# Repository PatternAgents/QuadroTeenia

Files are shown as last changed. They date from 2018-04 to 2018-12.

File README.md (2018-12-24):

# QuadroTeenia - A multi-channel, polymorphic audio module

Deprecated - see [Spoken into the Void](https://github.com/PatternAgents/SitV) for the current development version!



Format : ERA / Eurorack / (Dual) Breadboard Friendly

Height : 3U 

Width: 16HP

Depth : 1.0 cm

Power : +5V (USB) 200mA

Jacks : 3.5mm Jacks (CUI SJ1)

The QuadroTeenia is a low cost, embeddable audio module based on the Teensy 3.5/3.6 from PJRC :

* Embedded Rack Architecture (Eurorack 3U/16HP compatible)
* Teensy 3.6 Based (32 bit 180 MHz ARM Cortex-M4 processor with floating point unit and DSP)
* USB Full-Speed Device (USB Audio, MIDI, COM, HID)
* USB Full-Speed Host (USB Keyboard, peripherals)
* Two  (2) AC coupled, line level audio input channels 
* Four (4) AC coupled, line level audio output channels
* Four (4) DC coupled, ADC input channels
* Four (4) DC coupled, DAC output channels
* Four (4) DC coupled  Trigger input channels
* Four (4) DC coupled  Trigger output channels
* Dual (2) Flash/SRAM footprints for audio buffer (delay, echo, loop) memeories
* NVSRAM (non-volatile memory) for configuration memory (Embedis support)
* WS2812 Programmable RGB LED with output chain drivers
* Add optional "Quadro" boards for ERA and Eurorack jacks and interfaces
* Add optional Front-Panel board for mounting in ERA and/or Eurorack enclosures

QuadroTeenia Midi (https://www.youtube.com/watch?v=CV_AIyOy-t4)

QuadroTeenia (https://www.youtube.com/watch?v=xMB5RRlq_T8)

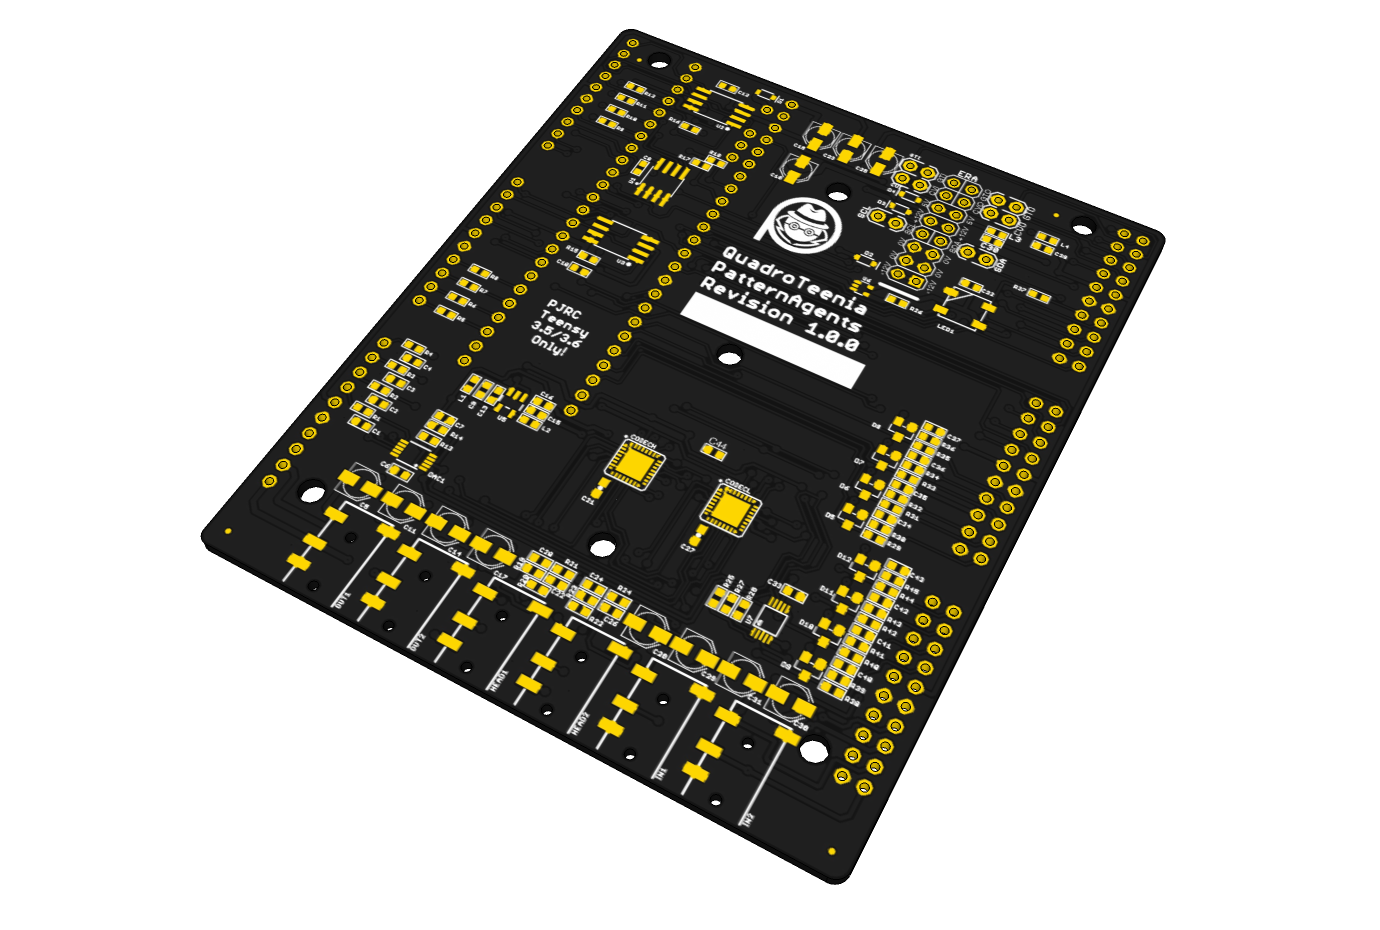
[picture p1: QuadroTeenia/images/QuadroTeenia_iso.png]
patternagents QuadroTeenia
[QuadroTeenia](https://github.com/patternagents/QuadroTeenia)

---------------------------------------
## QuadroTeenia Applications <a name="QuadroTeenia_Applications"/>

* Audio record/playback "trigger" device - 
  record/play samples based on external triggers

Add "Quadro" optional components and boards for :
* USB/MIDI to Eurorack Audio/CV/Control/Trigger
* Eurorack Multi-Sample Player
* Eurorack Sequencer
* Eurorack Reverb/Echo/Delay/Flanger (add SRAM)
* Eurorack Complex Filter (add SRAM)

---------------------------------------
## QuadroTeenia Status <a name="QuadroTeenia_Status"/>

**4/06/2018:** 
Revision 1.0.0 - Initial Layout received from OSHpark

**5/1/2018:**
Revision 1.0.0 
1) About 90% functional on first revision.
2) SGTL5000 routes too long, footprint issues, not functional

**5/11/2018:**
Revision 1.0.0
1) Midi I/O running, initial Midi-CV app

---------------------------------------
## QuadroTeenia Model Images

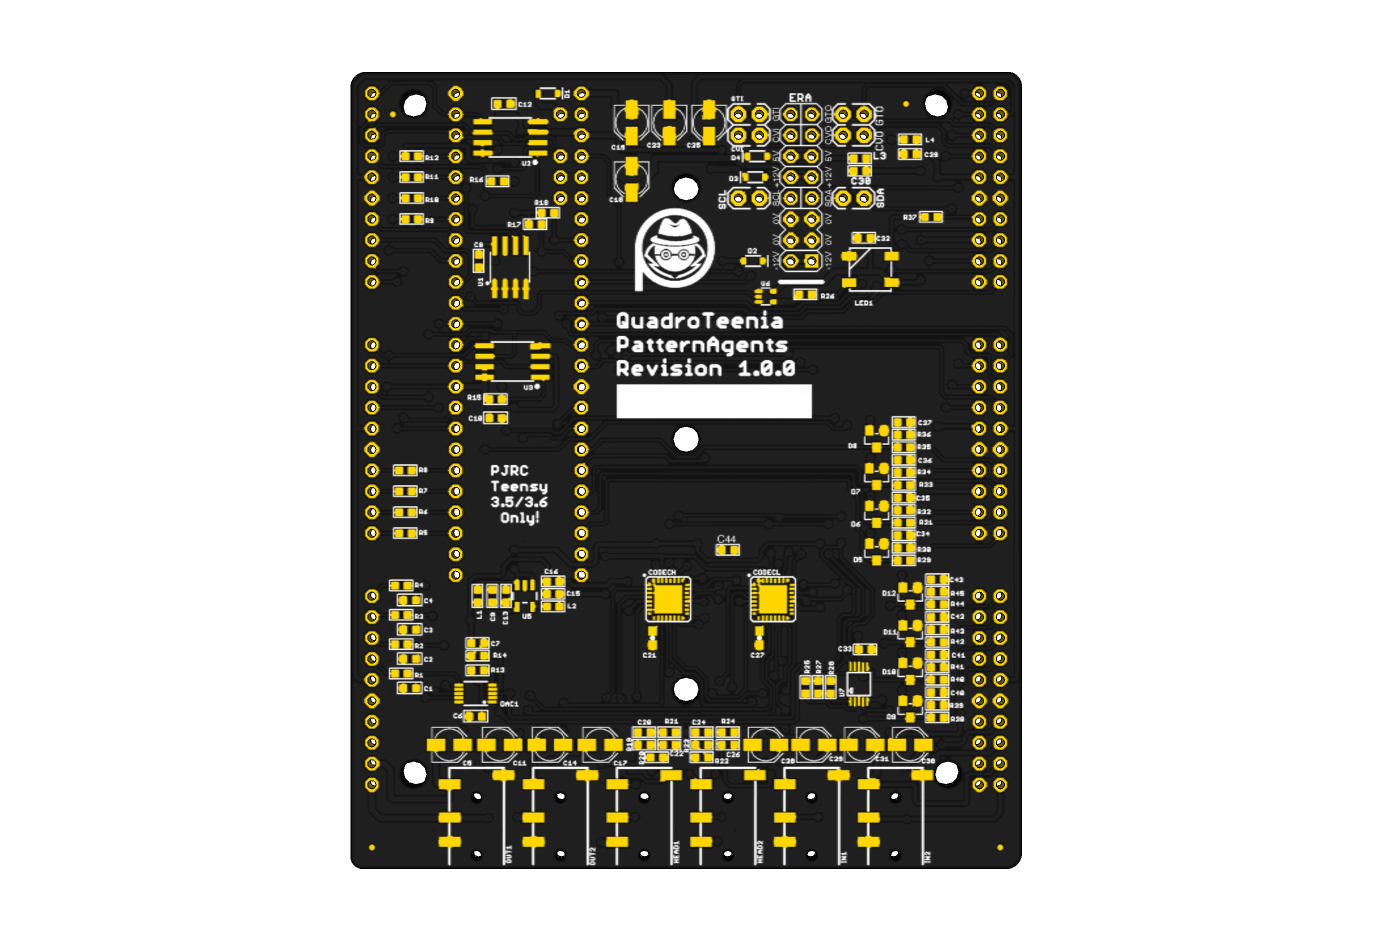
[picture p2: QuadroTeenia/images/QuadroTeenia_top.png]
patternagents QuadroTeenia
[QuadroTeenia](https://github.com/patternagents/QuadroTeenia)

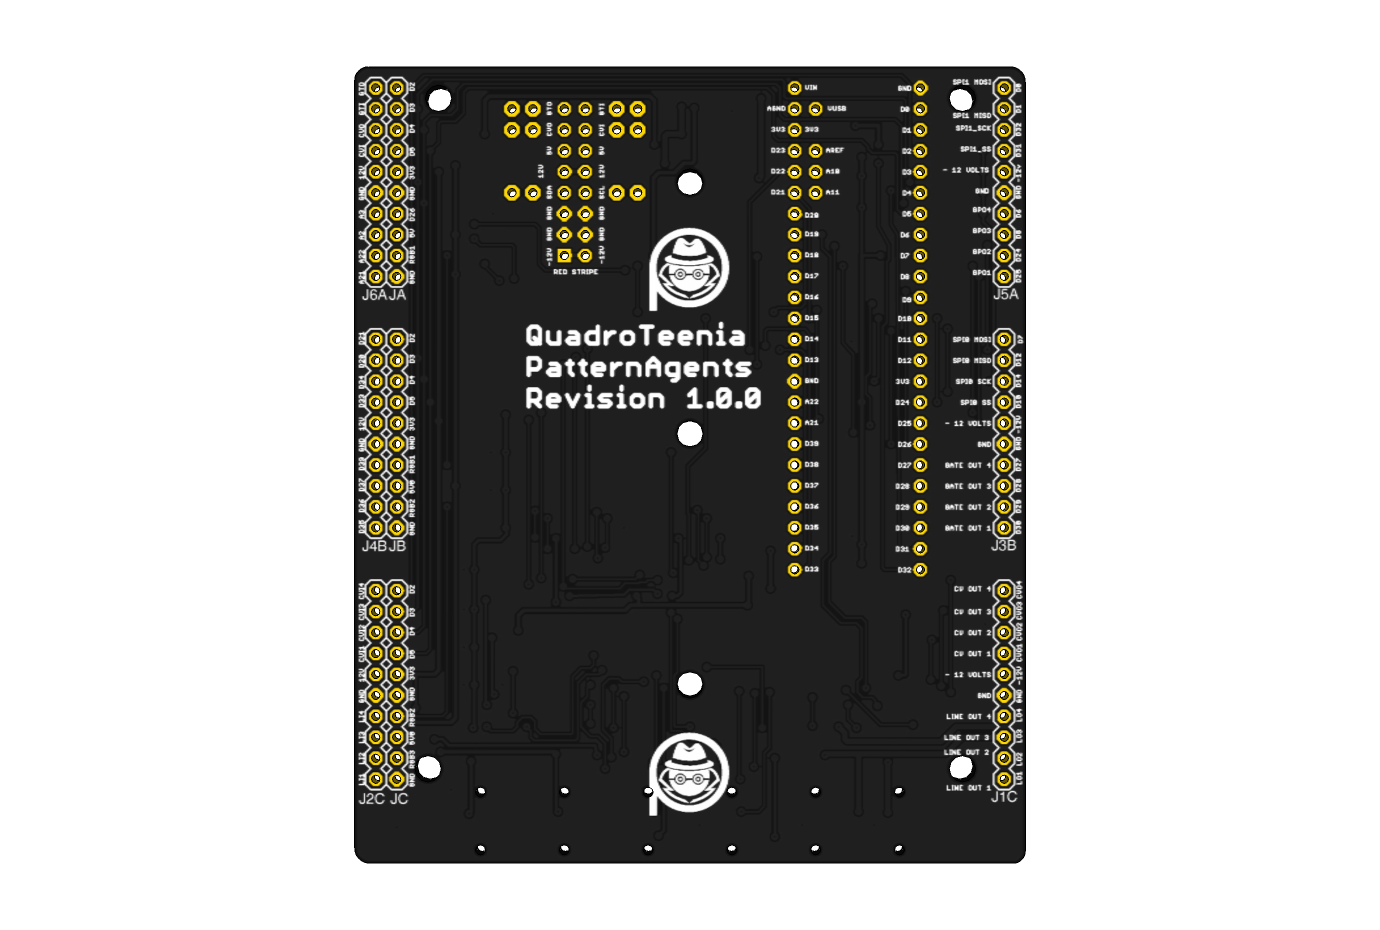
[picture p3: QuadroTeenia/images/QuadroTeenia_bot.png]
patternagents QuadroTeenia
[QuadroTeenia](https://github.com/patternagents/QuadroTeenia)

---------------------------------------

## QuadroTeenia Documentation Index <a name="QuadroTeenia_documentation_index"/>

[QuadroTeenia Project](https://github.com/PatternAgents/QuadroTeenia)

[QuadroTeenia Hardware](https://github.com/patternagents/QuadroTeenia/tree/master/QuadroTeenia/revisions/R1_0_0/)

---------------------------------------

## Documentation Index <a name="documentation_index"/>

[Organization Website](http://patternagents.github.io)

[FAQ - Frequently Asked Questions](http://thingsoc.github.io/support/faq.html)

---------------------------------------

[thingSoC 
*PatternAgents, LLC*](http://thingsoc.github.io)

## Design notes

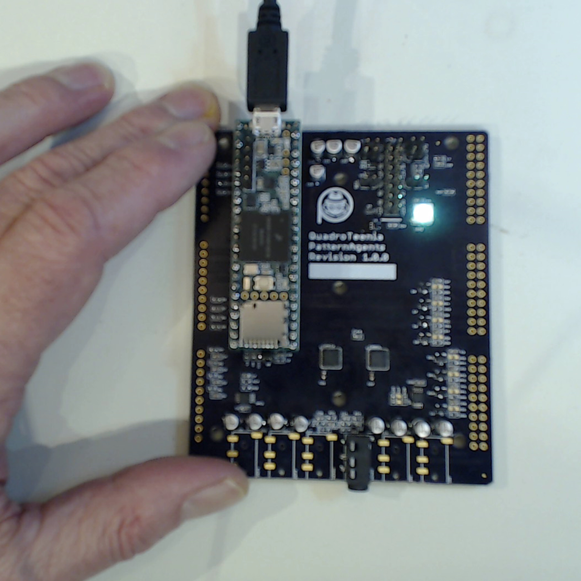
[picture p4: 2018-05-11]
QuadroTeenia/images/QuadroTeenia_Day1.png

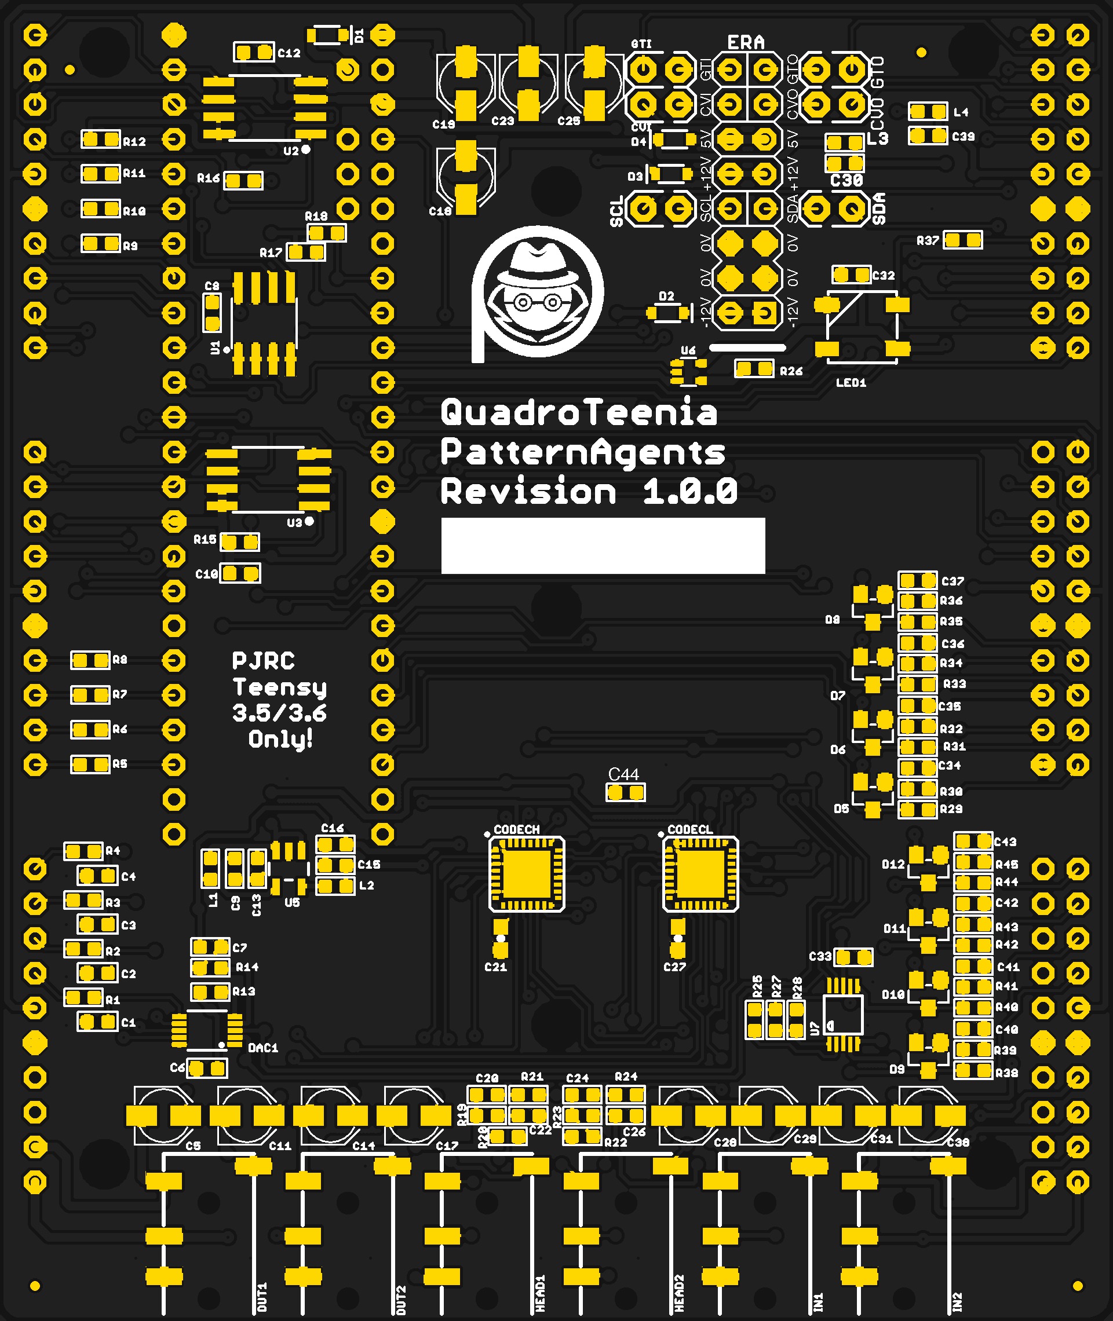
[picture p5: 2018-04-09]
QuadroTeenia/eagleUp/eagleUp_QuadroTeenia_board_top.jpg

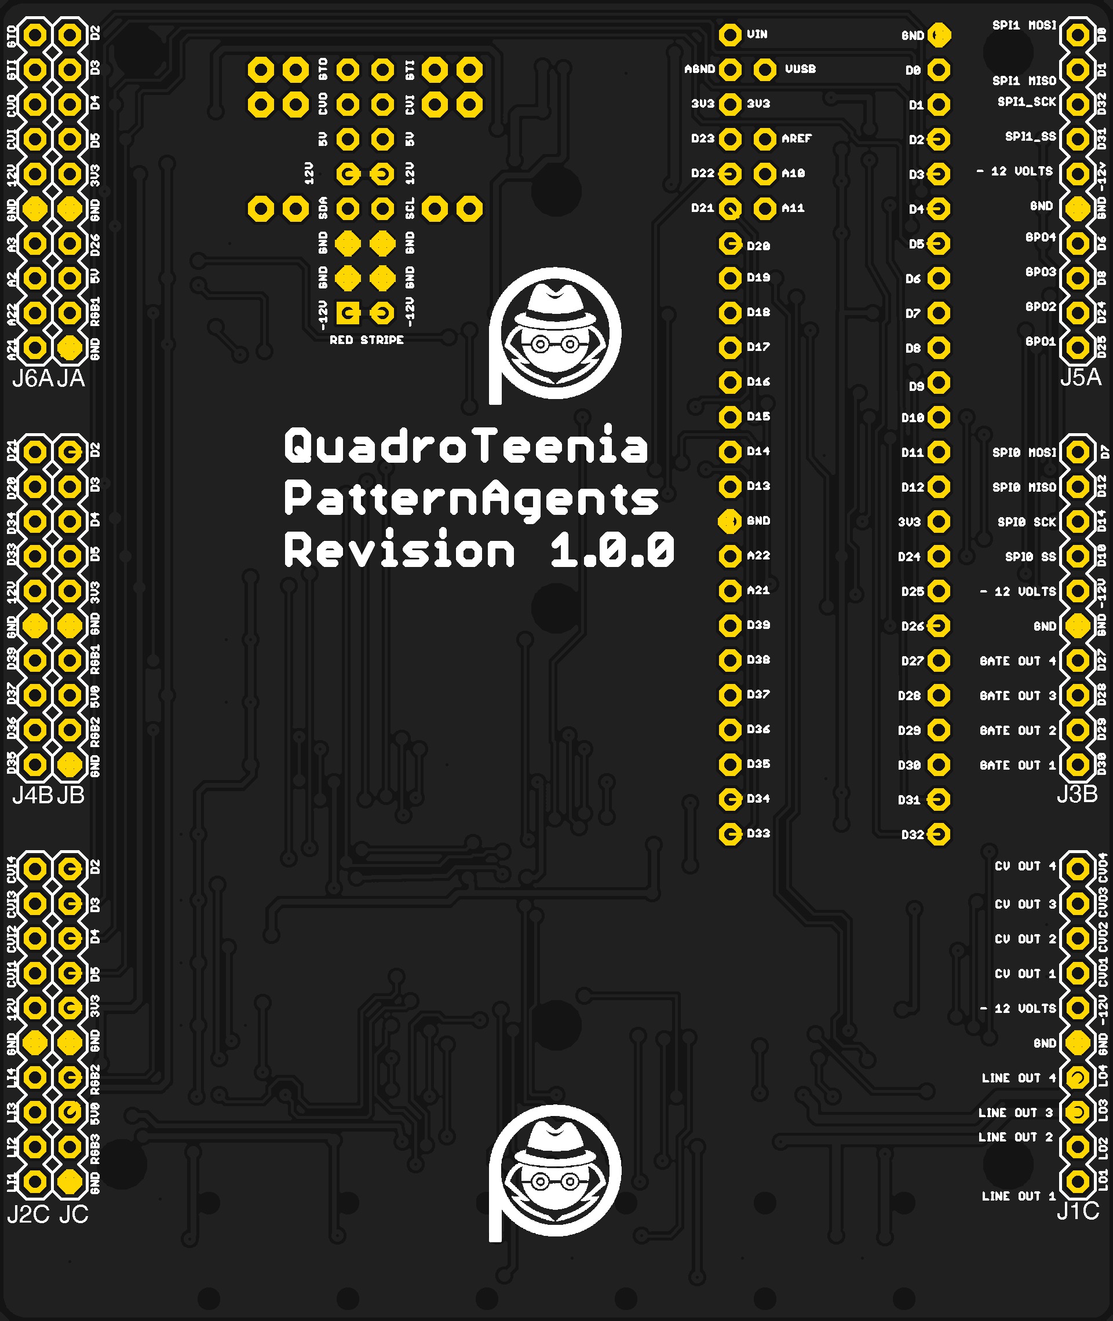
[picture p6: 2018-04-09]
QuadroTeenia/eagleUp/eagleUp_QuadroTeenia_board_bottom.jpg

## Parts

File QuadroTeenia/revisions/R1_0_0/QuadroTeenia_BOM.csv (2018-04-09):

Qty | Value | Device | Package | Parts | Description
12 |  | CAP-POL-B | PANASONIC_B | C5, C11, C14, C17, C18, C19, C23, C25, C28, C29, C31, C38 | Aluminum Electrolytic C""
9 |  | M10SILK_FEMALE_PTH | 1X10_OCTO | J1C, J2C, J3B, J4B, J5A, J6A, JA, JB, JC | Header 10
1 |  | WS2812B | WS2812B | LED1 | WS2812B - Intelligent control LED integrated light source
2 | 0.15uF | CAP0603-CAP | 0603-CAP | C21, C27 | Capacitor
7 | 0.1uF | CAPACITOR-0.1UF | C0603 | C1, C2, C3, C4, C6, C10, C12
4 | 0.5A/40V/420mV | DIODE-SCHOTTKY-PMEG4005EJ | SOD-323 | D1, D2, D3, D4 | Schottky diode
10 | 100K | SMD-RES-100K-1%-1/10W(0603) | R0603 | R13, R14, R29, R31, R33, R35, R38, R40, R42, R44 | 301010196
2 | 100R | SMD-RES-100R-5%-1/10W(0603) | R0603 | R26, R37 | 301010090
3 | 100nf | CERAMIC-100NF-50V-10%-X7R(0603) | C0603 | C8, C9, C33 | 302010138
2 | 10K | SMD-RES-10K-1%-1/10W(0603) | R0603 | R15, R16 | 301010299
4 | 10K 1/10W | SMD-RES-10K-5%-1/10W(0603) | R0603 | R9, R12, R25, R28 | 301010293
8 | 10nf | CERAMIC-10NF-50V-10%-X7R(0603) | C0603 | C34, C35, C36, C37, C40, C41, C42, C43 | 302010140
6 | 10uf | CERAMIC-10UF-10V-10%-X5R(0603) | C0603 | C7, C13, C15, C30, C32, C39 | 302010103
1 | 120OHM-500MA | SMD-FERRITE-CHIP-120-OHM-500MA(0603) | L0603 | L3 | 303030001
1 | 1uf | CERAMIC-1UF-25V-10%-X7R(0603) | C0603 | C16 | 302010139
6 | 2.2K | SMD-RES-2.2K-5%-1/10W(0603) | R0603 | R10, R11, R17, R18, R19, R23 | 301010124
5 | 2.2uf | CERAMIC-2.2UF-10V-10%-X7R(0603) | C0603 | C20, C22, C24, C26, C44 | 302010054
8 | 220R | SMD-RES-220R-5%-1/10W(0603) | R0603 | R1, R2, R3, R4, R5, R6, R7, R8 | 301010163
2 | 25F32006WSOI | SPI_FLASH-X25XXSMD1 | SO08-EIAJ | U2, U3 | 32M Serial Flash Memory
6 | 2p-2.54 | JMP-2-NO-PTH | JMP-2-NO-PTH-2.54 | CVI, CVO, GTI, GTO, SCL, SDA | Two Terminal Jumper - Normally Open
3 | 330OHM-500MA | SMD-FERRITE-CHIP-120-OHM-500MA(0603) | L0603 | L1, L2, L4 | 303030001
2 | 330R | SMD-RES-330R-1%-1/10W(0603) | R0603 | R21, R24 | 301010300
2 | 47K | SMD-RES-47K-5%-1/10W(0603) | R0603 | R20, R22 | 301010084
1 | 74LVT1G125DCK | 74LVT1G125DCK | SC70-5 | U6 | Single Bus Buffer Gate with 3-State Output
1 | ADS1115IDGST | ADC_ADS1015 | MSOP10 | U7 | ADS1015 - 12-bit 4-Channel I2C ADC with Internal PGA
1 | AP2112K-1.8V | V_REG_LDOSMD | SOT23-5 | U5 | Voltage Regulator LDO
6 | AUDIO_JACK_TRRSSMD_RA | AUDIO_JACK_TRRSSMD_RA | AUDIO_JACK_3.5MM_TRRS_SMD_RA | HEAD1, HEAD2, IN1, IN2, OUT1, OUT2 | Audio Jack - 3.5mm TRRS (SMD)
8 | BAT54S | BAT54S | SOT-23 | D5, D6, D7, D8, D9, D10, D11, D12
1 | DNP | SMD-RES-10K-5%-1/10W(0603) | R0603 | R27 | 301010293
8 | DNP | SMD-RES-200K-5%-1/10W(0603) | R0603 | R30, R32, R34, R36, R39, R41, R43, R45 | 301010212
1 | ERA-NOS | ERA-NOS | ERA-OPEN | ERA | EuroRack2 - Backplane Connector
4 | FIDUCIALUFIDUCIAL | FIDUCIALUFIDUCIAL | MICRO-FIDUCIAL | FID1, FID2, FID3, FID4 | Fiducial Alignment Points
1 | FM24W256-G | FM24W256-G | SO08 | U1 | I2C FRAM FM24W256
1 | MCP4728T-E | MCP4728T-E | MSOP10 | DAC1 | MCP472812-Bit, Quad Digital-to-Analog Converter with EEPROM Memory
3 | PA_LOGO_SYMLARGE | PA_LOGO_SYMLARGE | PA_LOGO_AGENT_LRG_SYM | $$U$1, U$100, U$101 | PatternAgents Logo Symbol
2 | SGTL5000-32 | SGTL5000-32 | QFN-32-5MM | CODECH, CODECL
1 | TEENSY_3.5/3.6_BASIC | TEENSY_3.5/3.6_BASIC | TEENSY_3.5/3.6_BASIC | U4

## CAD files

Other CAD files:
QuadroTeenia/eagleUp/QuadroTeenia.skp
QuadroTeenia/revisions/R1_0_0/eagleUp/QuadroTeenia.skp

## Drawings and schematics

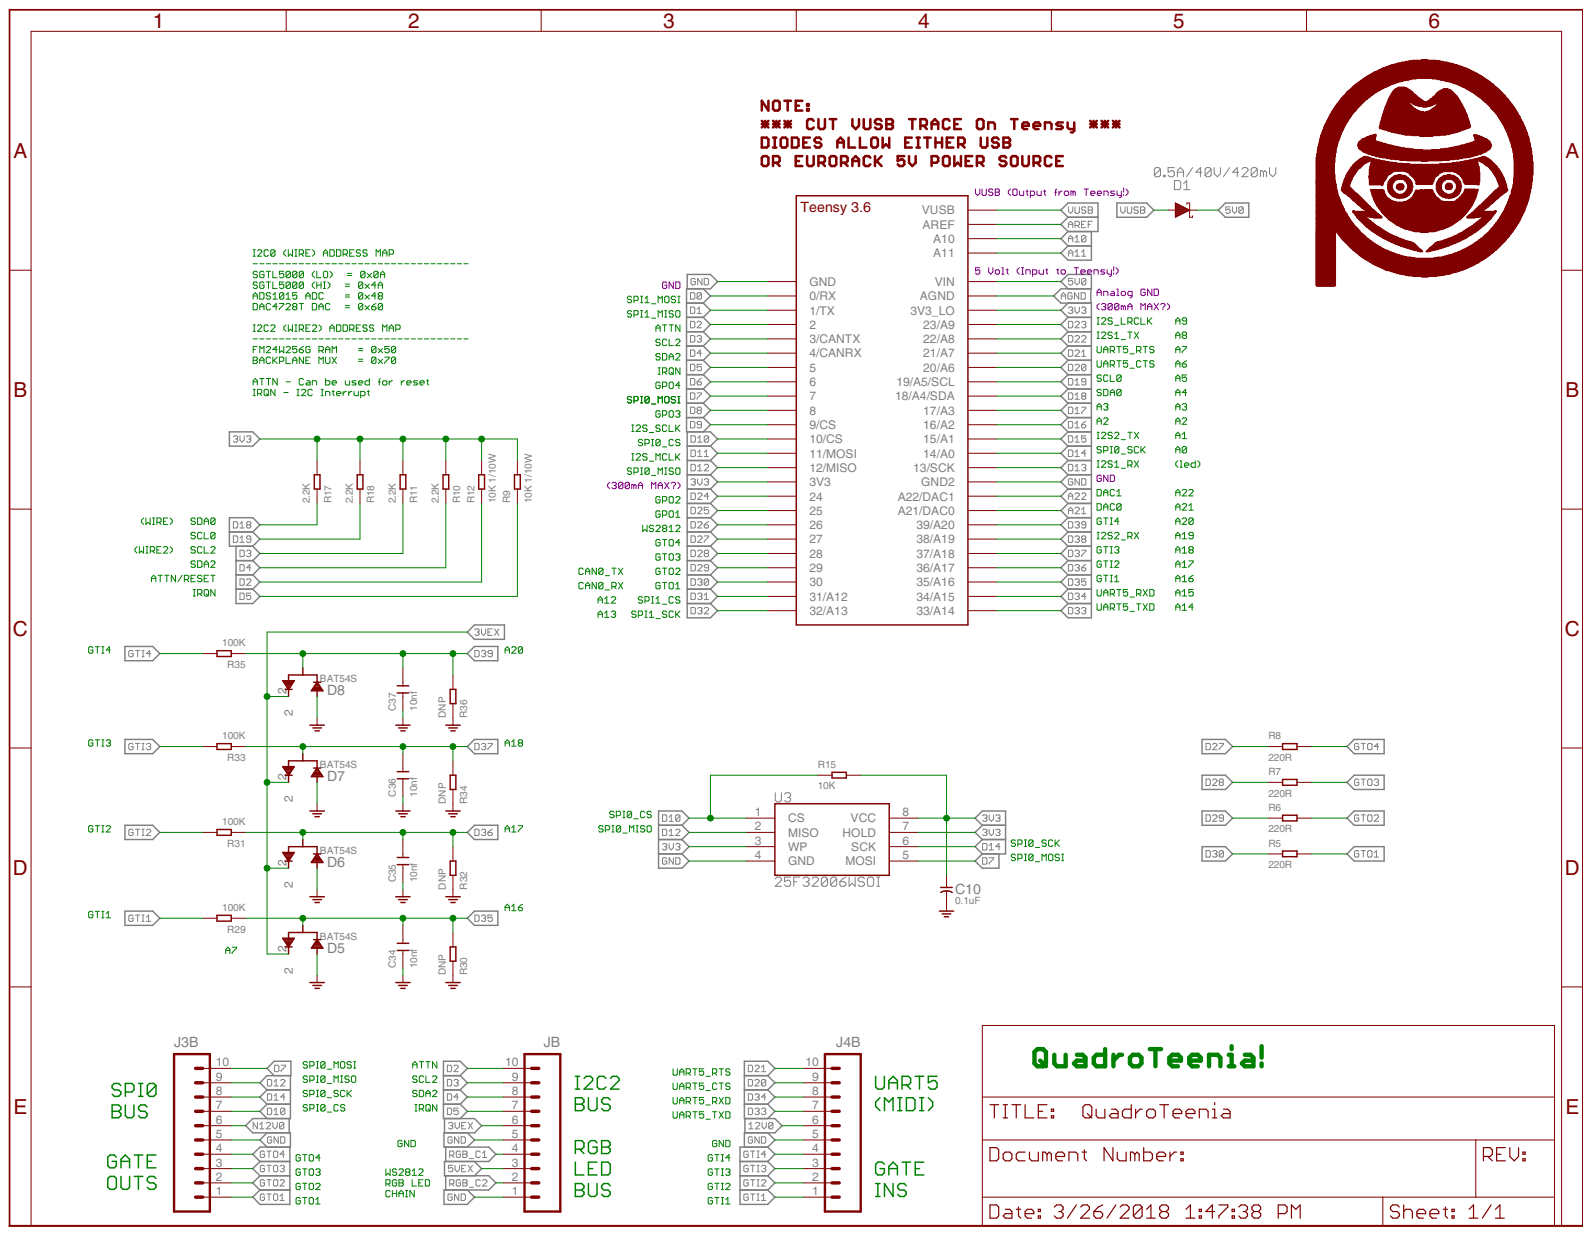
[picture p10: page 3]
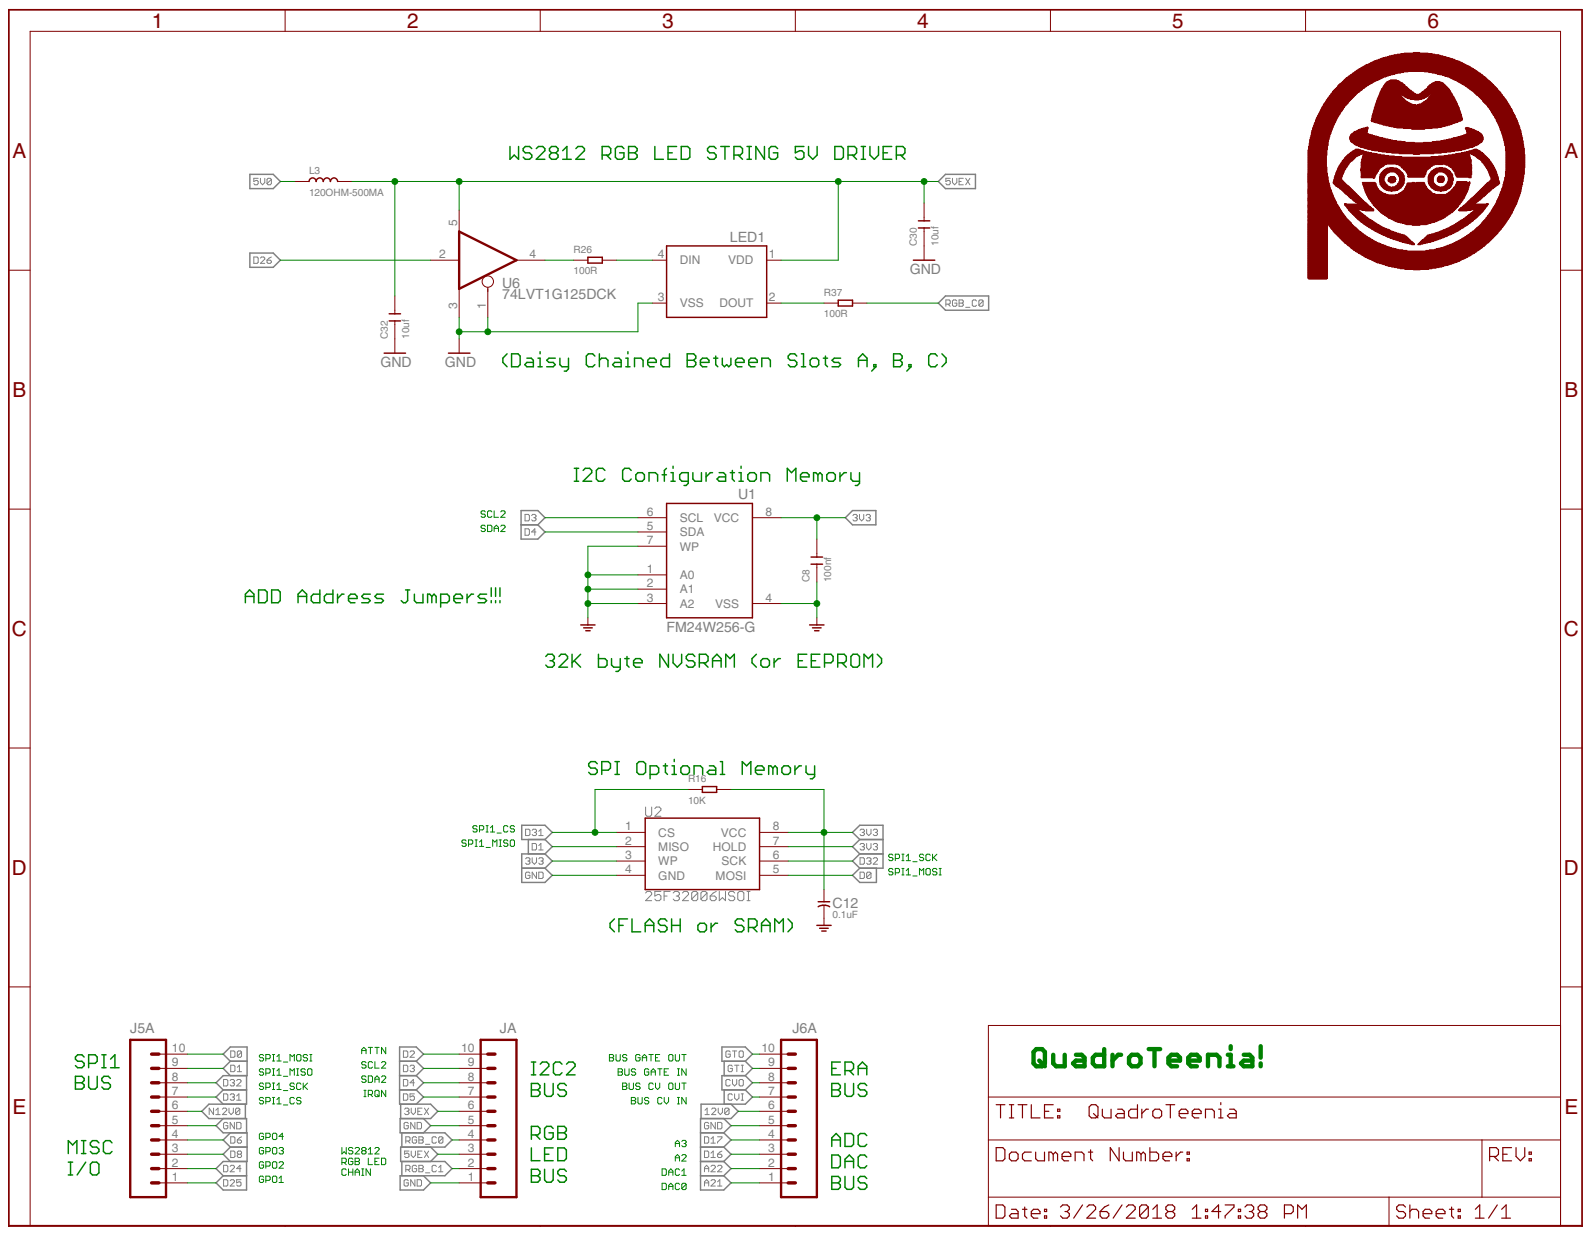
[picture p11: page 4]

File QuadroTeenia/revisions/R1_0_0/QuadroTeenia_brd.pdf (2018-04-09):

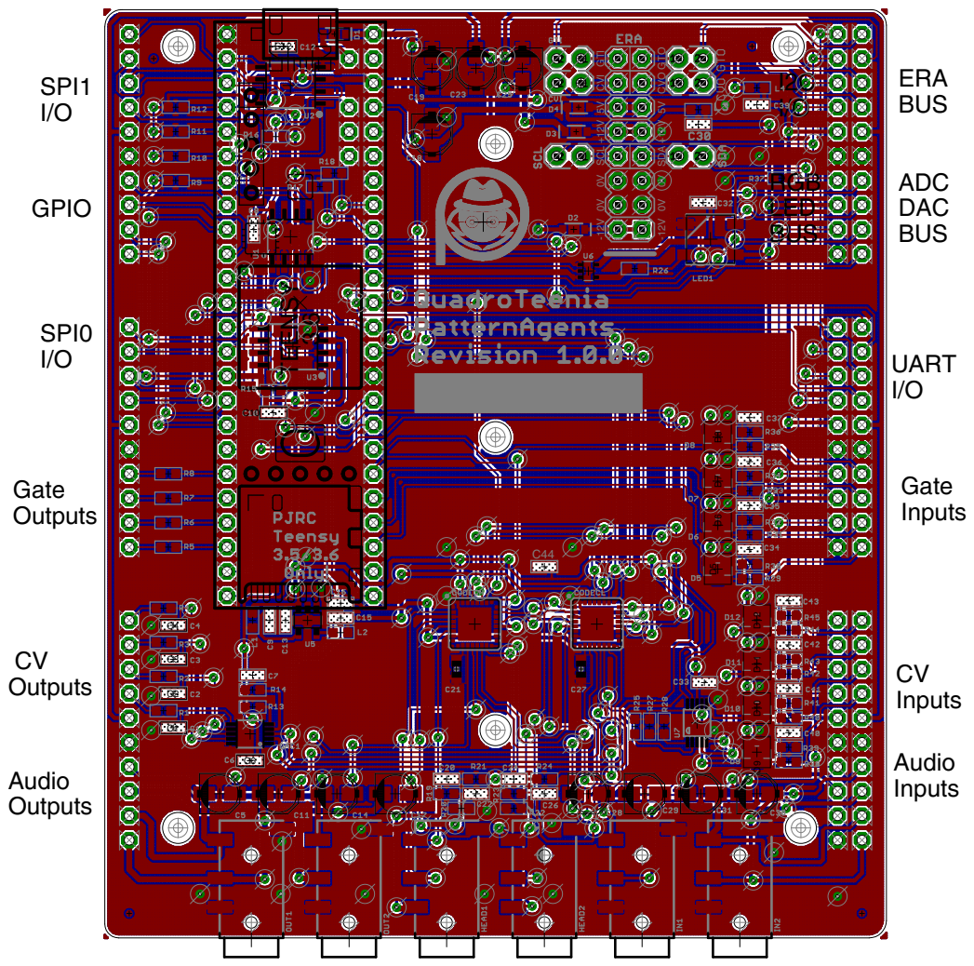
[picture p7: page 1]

C1J B4J C2J B3J A5J AJ A6J BJCJ +12V -12V 5V CVO GTO -12V 0V0V SCL SDA +12V 5V 0V0V CVI GTI Audio Inputs CVInputs Gate Inputs Gate Outputs CV Outputs Audio Outputs GPIO ADC DAC BUS SPI0 I/OSPI1 I/O I2CI/O UART I/OERA BUS RGB LED BUS C10 C6 C4C3C2C1 D9 D10 D11 D12 C12 D5 D6 D7 D8 TEENSY 3.6 C44

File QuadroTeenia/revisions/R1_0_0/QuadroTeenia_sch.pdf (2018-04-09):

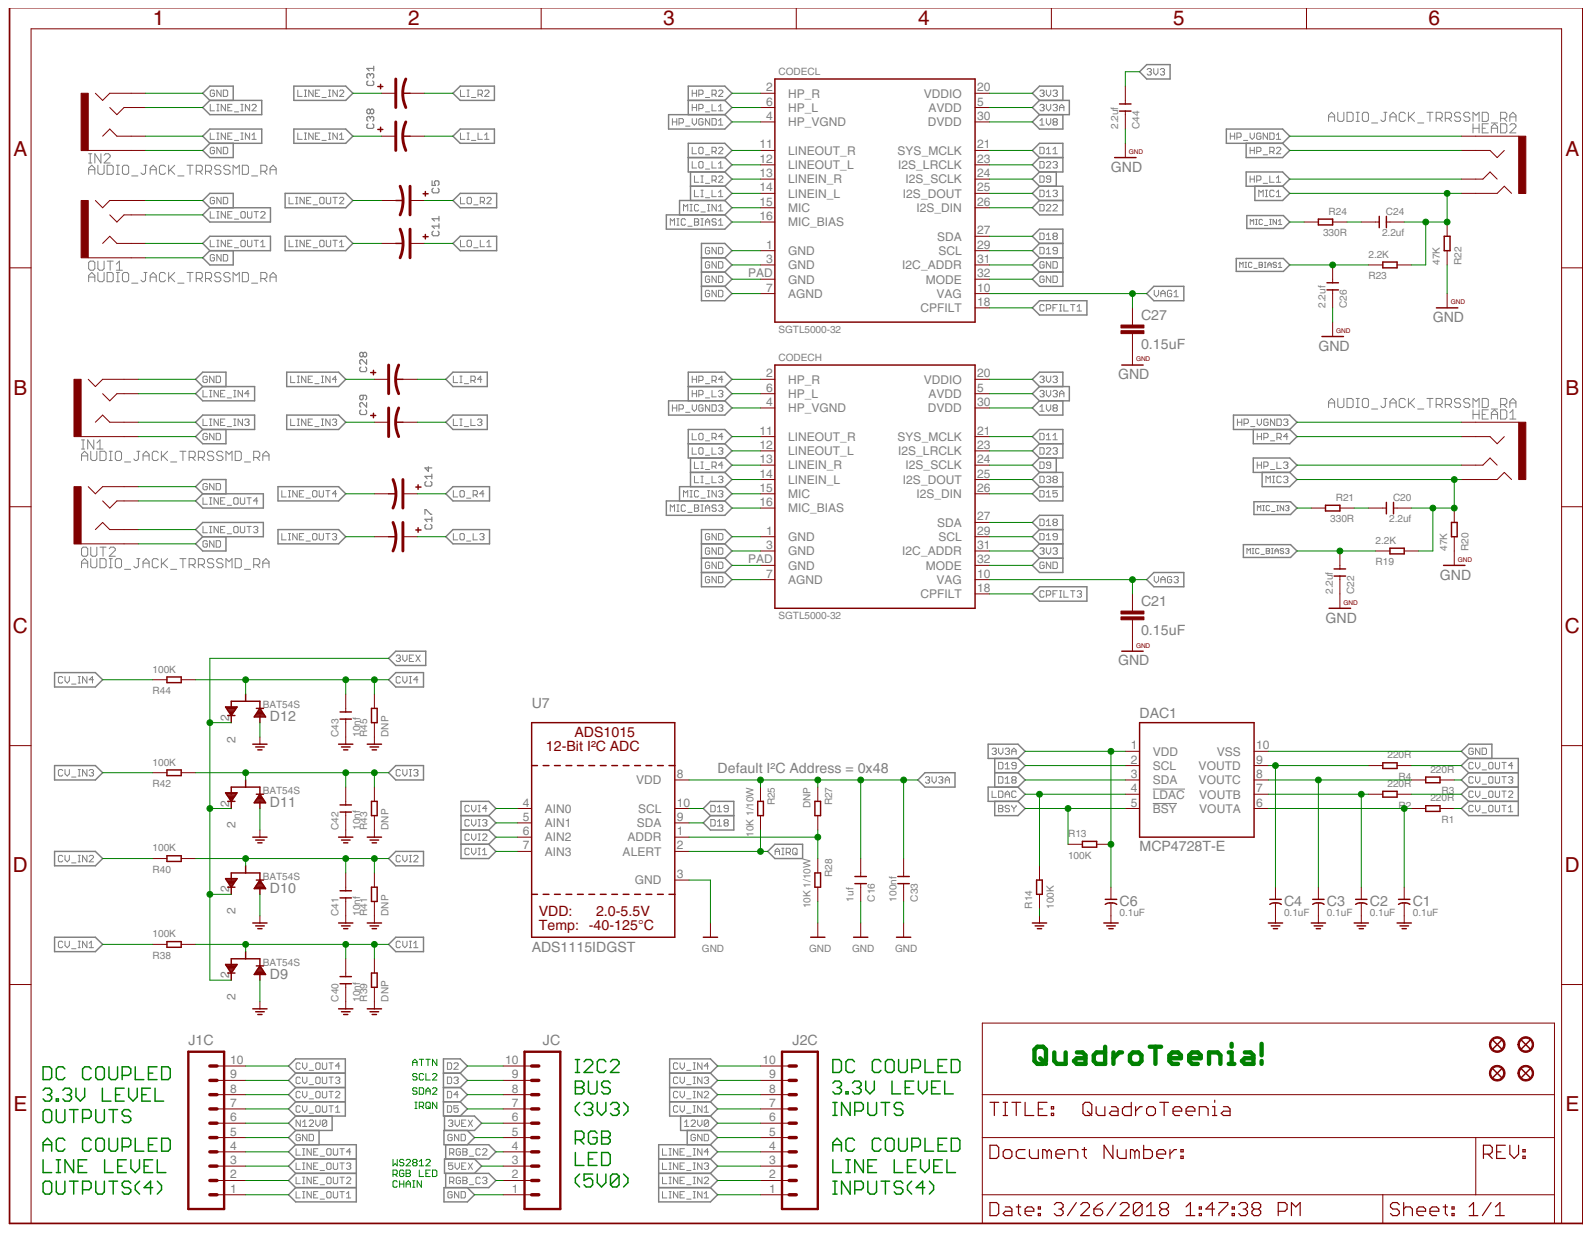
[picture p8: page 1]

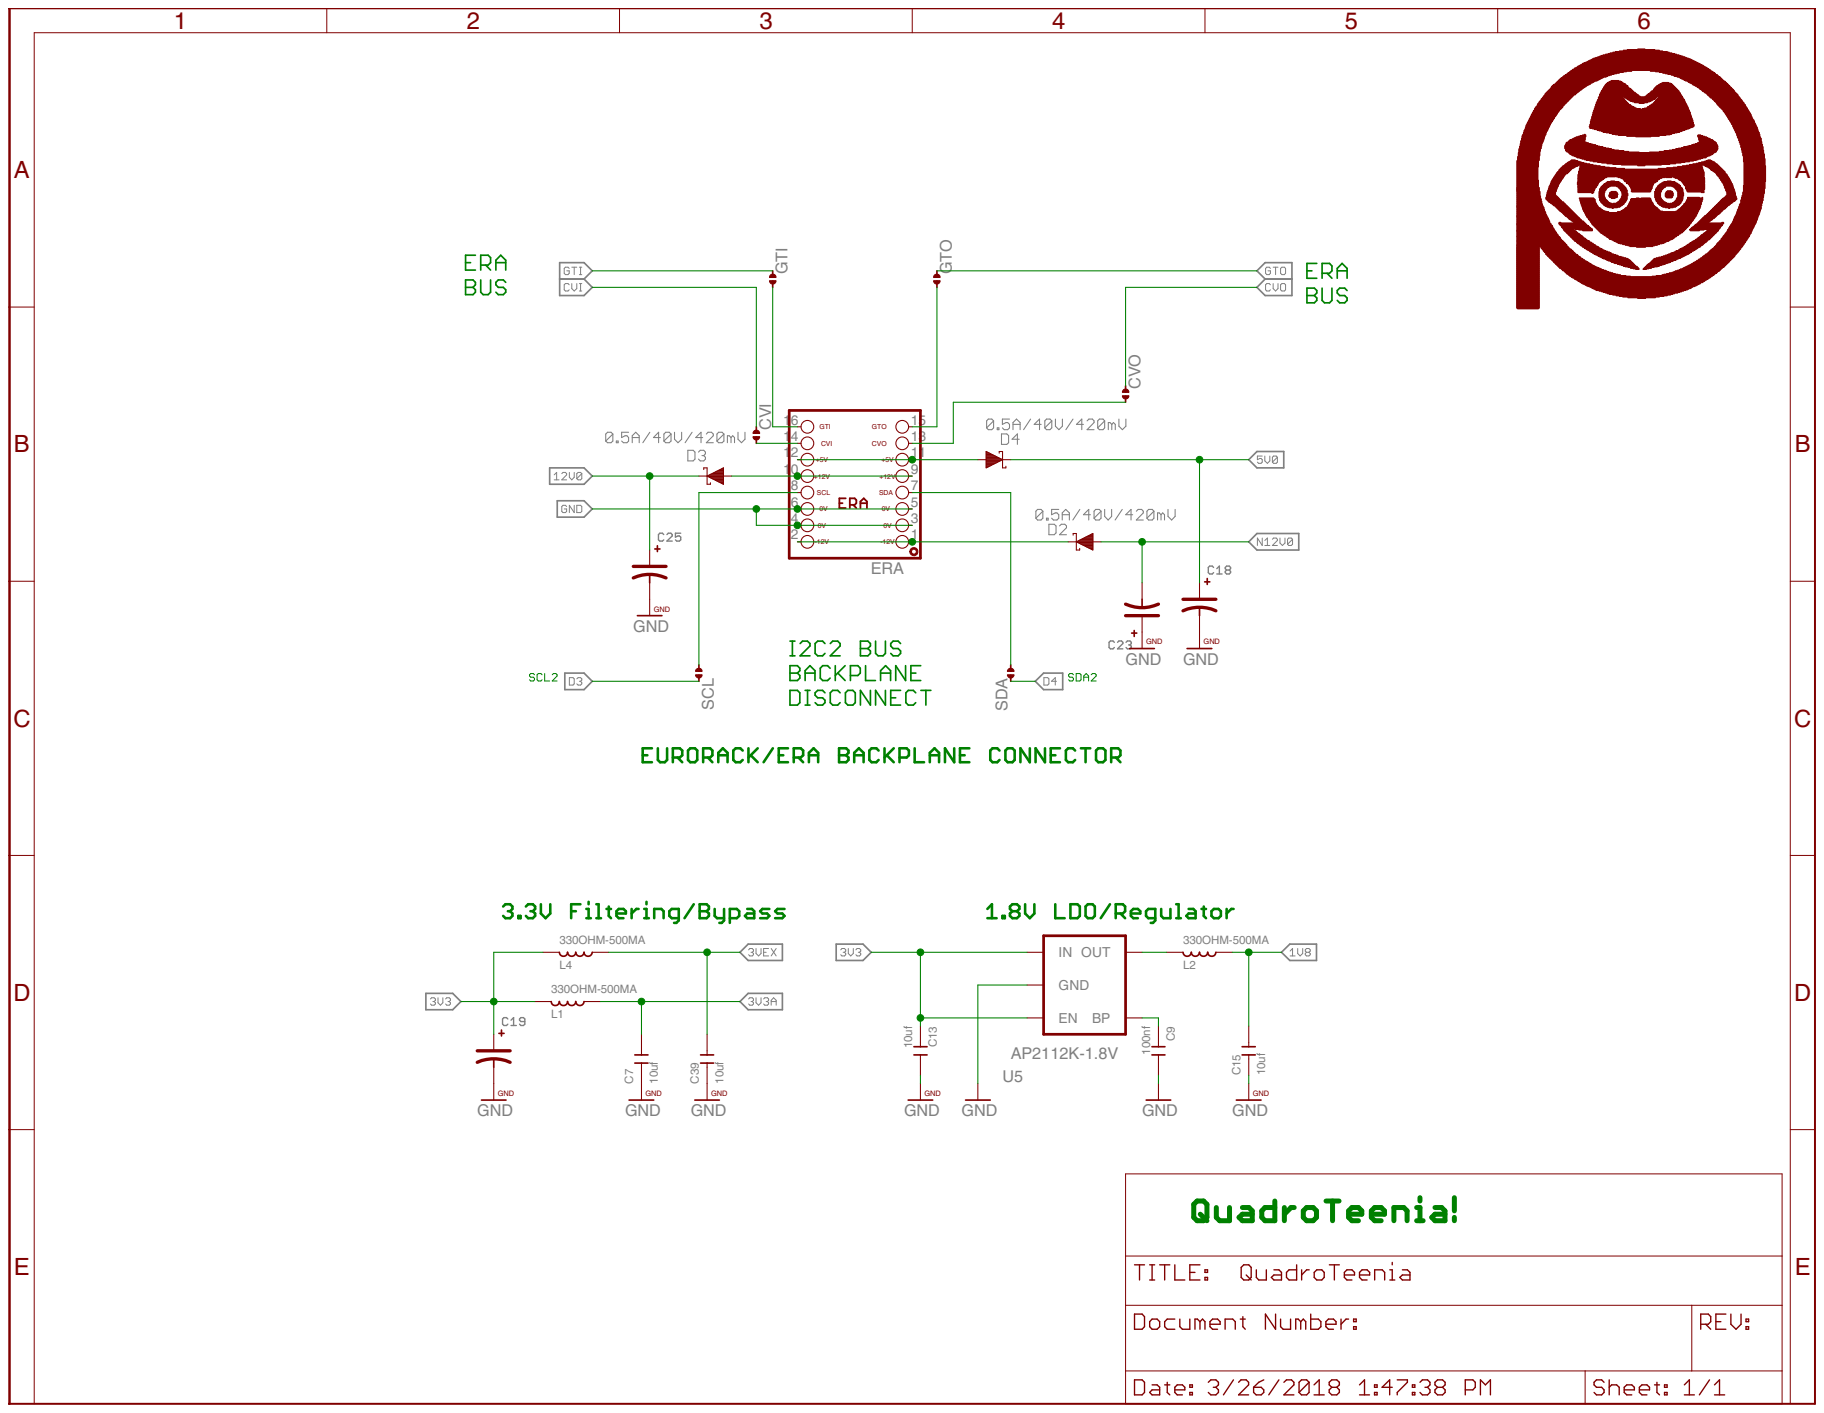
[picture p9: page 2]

6 5
4 3 0V 0V

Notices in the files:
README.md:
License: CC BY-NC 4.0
